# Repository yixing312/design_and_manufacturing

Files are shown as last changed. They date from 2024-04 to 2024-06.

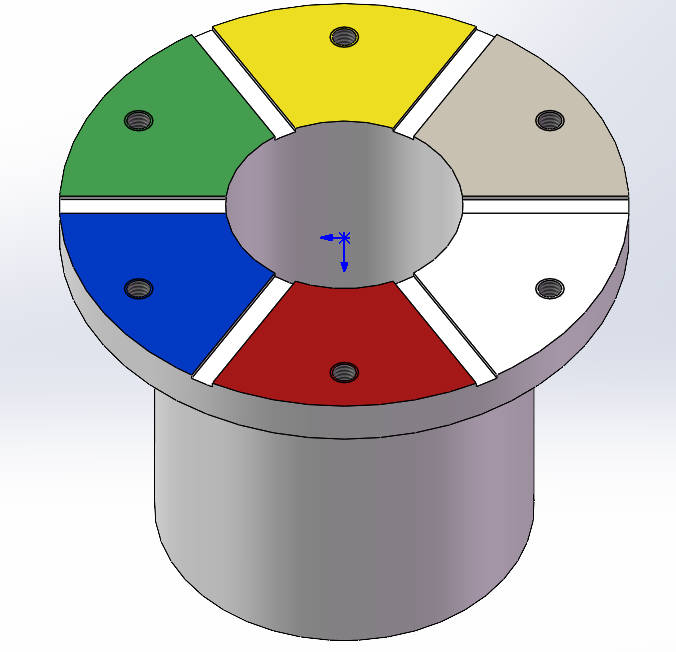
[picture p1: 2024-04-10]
建模文件/model_ver3/下法兰.jpg

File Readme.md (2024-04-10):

# README

## 文件结构

- 绘图文件
- 建模文件
- 任务说明文件
- 周期汇报
- Ansys
- data
  - Ansys
    - [4 4 4 4 4 4]
  - task_queue.txt
- scripts
  - py端分析器
  - Ansys端分析器

## 双端分析器执行逻辑

- **在 py 中运行 `py端分析器.py`**

`py端分析器.py` 中包含一个任务队列 `task_queue`，一个任务栈 `task_stack`。任务队列中存放待执行的任务，任务栈中存放已经分析完成的任务。每个任务元素都是由六个数字表示的元组，分别表示六个螺栓参数。

`py端分析器.py`持续循环查找 `"../data/task_queue.txt"` 文件，将该文件消失视为ansys分析完成，此时弹出任务队列中的元素，依次分析同轴度并压入 `ansys_ans` 栈中。将任务队列完成的任务压入任务栈中。

根据任务栈和分析结果栈中的数据，梯度下降获得下一组任务参数，将其压入任务队列中。

将任务队列写入 `"../data/task_queue.txt"` 文件，等待下一次循环。

在等待循环的过程中利用空闲时间完成上一个周期内任务的分析结果绘图等后处理工作。

- **在 Ansys 中运行 `ansys端分析器.py`**

`ansys` 中不指定初始任务，而是持续循环查找 `"../data/task_queue.txt"` 文件，将该文件出现视为py端分析完成，开始执行分析任务。

文件中每一行即为一个单独的任务，为一个元组，包括六个螺栓参数。由于读取每一行为一个字符串，可采用 `task[1:-1]..strip().split(",")` 函数将其转化为元组。

在分析完成后，将每个任务的分析结果写入 `"../data/" + str(task)` 文件中，等待py端读取。**注意，这里没有后缀，本质上就是txt文件**

完成所有分析任务后删除 `"../data/task_queue.txt"` 文件，等待下一次循环。

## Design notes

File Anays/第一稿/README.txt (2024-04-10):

by zsb ver1

1、建模导入的是zhgg的ver2版本，整体仿真参数设置过程与PPT一致

2、命名选择中，各螺栓序号与sw文件中螺栓序号一致，为7-12。用到命名选择的面有：各螺栓下表面(boltx_down)、上法兰上表面(up_up)、各螺栓
螺纹面(bolt_x)、下法兰螺纹孔内表面(down_x)、上法兰扇面(up_X)、下法兰扇面(down_X)

3、目前仿真求解项有整体总变形，以及自定义的一个截面上x方向变形量，还不能得到同轴度

4、子部件id：
bolt11 	209
bolt8  	211
bolt9	213
bolt10	215
bolt7	217
bolt12	219
获取方法：示教

5、自动化：利用文件中的calculate.py脚本，保存的结果路径为：ansys_1_files/user_files/

by the way ANSYS参数设置真麻烦啊啊啊啊啊啊

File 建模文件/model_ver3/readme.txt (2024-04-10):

Modeled by mzh, ver 3

1.原以为建模三分钟完成，后来发现因为六个扇形面高度均不一样，需要分6部分建模，稍微有点点麻烦╰（‵□′）╯

2.上下法兰均分成了6个单独的扇形，因此每个扇形（包括6条切槽）均可独立设置高度，方便结合实物修改

3.在零件图的部件树中对每个扇形、切槽、螺纹孔进行了命名，方便查找，同时不同面的染色不同

4.A面染红色，依次顺时针（正对染色面）旋转为B、C、D、E、F面

5.各个扇形高度参考“实验室已有上下法兰接触面厚度尺寸”给定

6.assemble_1~6装配时均选取相对距离最近的两个面重合，因为这两个面间距最小，重合时其他面都不会干涉

7.螺栓采用“同轴心”和表面“重合”约束，并未采用“螺旋”配合，因此实际上会产生螺纹孔与螺栓干涉的问题，
   已经评估会影响仿真！

8.assemble装配体的螺栓螺纹线为实际建模，assemble_1~assemble_6的螺纹线不存在（光轴）

9.assemble_1部件树下的螺栓顺序与扇形顺序对应关系：
	螺栓顺序    上法兰面    下法兰面    间隙（以20mm为0距离）
	1	  A	    E	    0.237	(重合面)
	2	  C	    C	    0.345
	3	  D	    B	    0.365
	4	  F	    F	    0.389
	5	  E	    A	    0.398
	6	  B	    D	    0.425

  assemble_2部件树下的螺栓顺序与扇形顺序对应关系(通过干涉检查)：
	螺栓顺序    上法兰面    下法兰面    间隙（以20mm为0距离）
	1	  A	    A	    0.282	(重合面)
	2	  C	    E	    0.323
	3	  D	    D	    0.394
	4	  F	    B	    0.419
	5	  E	    C	    0.375
	6	  B	    F	    0.366

  assemble_3部件树下的螺栓顺序与扇形顺序对应关系(通过干涉检查)：
	螺栓顺序    上法兰面    下法兰面    间隙（以20mm为0距离）
	1	  A	    B	    0.341
	2	  C	    F	    0.397
	3	  D	    E	    0.261	(重合面)
	4	  F	    C	    0.337
	5	  E	    D	    0.486
	6	  B	    A	    0.337

  assemble_4部件树下的螺栓顺序与扇形顺序对应关系(通过干涉检查)：
	螺栓顺序    上法兰面    下法兰面    间隙（以20mm为0距离）
	1	  A	    C	    0.259	(重合面)
	2	  C	    A	    0.368
	3	  D	    F	    0.335
	4	  F	    D	    0.448
	5	  E	    E	    0.353
	6	  B	    B	    0.396

  assemble_5部件树下的螺栓顺序与扇形顺序对应关系(通过干涉检查)：
	螺栓顺序    上法兰面    下法兰面    间隙（以20mm为0距离）
	1	  A	    D	    0.37
	2	  C	    B	    0.427
	3	  D	    A	    0.306	(重合面)
	4	  F	    E	    0.315
	5	  E	    F	    0.427
	6	  B	    C	    0.314
   
  assemble_6部件树下的螺栓顺序与扇形顺序对应关系(通过干涉检查)：
	螺栓顺序    上法兰面    下法兰面    间隙（以20mm为0距离）
	1	  A	    F	    0.311
	2	  C	    D	    0.456
	3	  D	    C	    0.283	(重合面)
	4	  F	    A	    0.36
	5	  E	    B	    0.457
	6	  B	    E	    0.292

猜测：选取间隙方差最小的装配方式最有利于提高同轴度喵~

以上，喵喵喵ο(=•ω＜=)ρ⌒☆（爱来自小猫娘~~~~~~(❤ ω ❤)

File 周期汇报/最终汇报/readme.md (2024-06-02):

# 鸟为什么会飞

最后一次，我们要做出最好的装配。

分析与测试有什么意义？——为了能够以最少的时间完成一次完美的装配
每一次装配，都是为了未来的某一次可以以最小的成本呈现出结果

---
第一，赋其形骨
数字化是问题抽象的第一步。

---
第二，赋其翅翼
装配相位就不是问题啊，我们测试六次不就搞定了？仿真又没多少时间

一个循环对称的函数可以写成什么样的组合呢

对于六个变量的装配问题来说，显然有一个 C6 的旋转对称性和非手性，其拥有的6个自由度恰好可以有最小自由度描述如下，由一个二次型、一个线性向、一个常数项组成

$$
f = q^{T}\begin{bmatrix}
  a & b & c & d & c & b \\
  b & a & b & c & d & c \\
  c & b & a & b & c & d \\
  d & c & b & a & b & c \\
  c & b & c & b & a & b \\
  b & c & d & c & b & a \\
\end{bmatrix}q+eq+f
$$

$$
\phi _{\text{最优}} = \phi \quad for \quad \min_{\phi}\left( Var(d_{\phi;1:3})+\alpha E(d_{\phi;C_2})+\beta E(d_{\phi;C_3})\right)
$$

---
第三，赋其色彩
仿真那么多次是为了此后遇到同样的问题不再需要仿真

---
第四，试其飞翔
最后一次，高高的飞起来吧

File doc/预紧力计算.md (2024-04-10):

# 螺栓预紧力与扭矩的计算

——by mzh

在拧紧螺母时需要克服内、外螺纹之间的螺纹力矩$T_1$和螺纹连接件与被连接件之间的支承面摩擦力矩$T_2$的和力矩：
$$
T=T_{1}+T_{2}=\frac{d_{2}} {2} F_{p} \operatorname{t a n} ( \, \psi+\rho_{v} \, ) \,+\frac{1} {3} \mu_{c} F_{p} \, \frac{D_{0}^{3}-d_{0}^{3}} {D_{0}^{2}-d_{0}^{2}}
$$
其中$d_2$螺纹中径，$\psi$螺纹升角，$\rho_v$螺纹当量摩擦角，$\mu_c$螺母端面与被连接件支承面之间的摩擦系数，$D_0,d_0$支承面的内外径，$F_p$预紧力。

通过下图确定$\mu_c$



对于普通粗牙螺纹钢制螺栓，取$\psi=1°42^″—3°2^″$，$\rho_v=\arctan(1.155\mu_c)$,$\mu_c=0.15$,$d_2≈0.9d$，$D_0≈1.7d$,$d_0≈1.1d$，带入上式，整理可得：
$$
T≈0.2F_pd
$$
故当扭矩介于3—6Nm时，根据上式可以计算得到预紧力介于2500—5000N。

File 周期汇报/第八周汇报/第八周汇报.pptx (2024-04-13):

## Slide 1

装配问题

装配大作业

选择装配相位

设置装配应力

迭代装配应力

处理分析结果

确定装配方案

Ansys

装配描述

建模文件

图纸文件

Python

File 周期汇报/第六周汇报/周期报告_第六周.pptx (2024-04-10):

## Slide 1

周期汇报
——第六周

闫济洲 张善斌 马正华

2024年4月6日

## 制图与建模

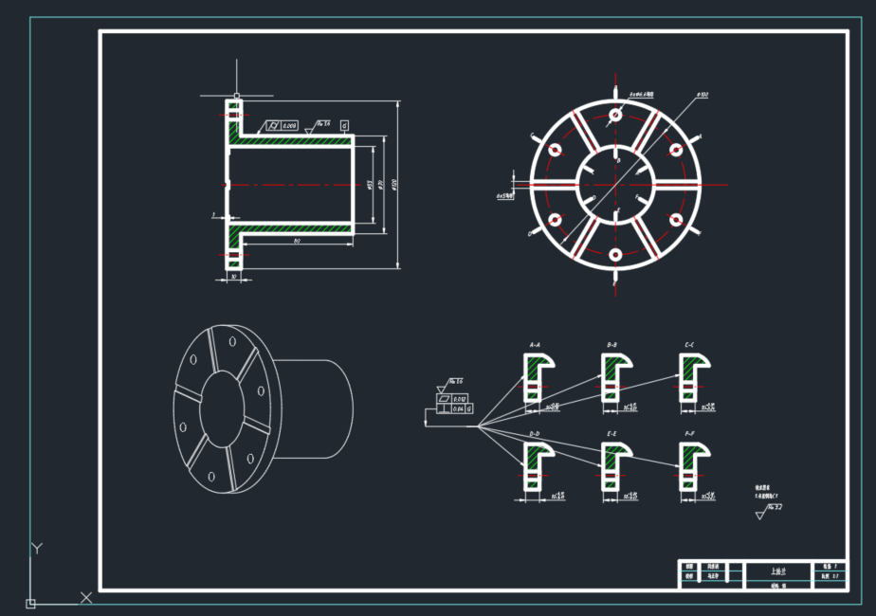
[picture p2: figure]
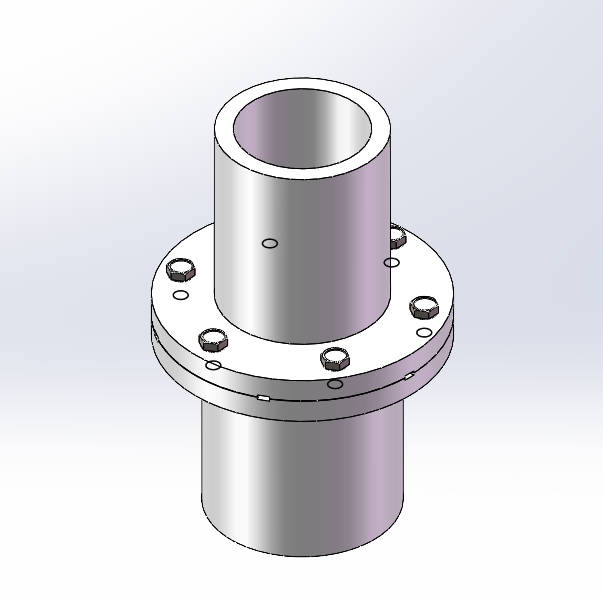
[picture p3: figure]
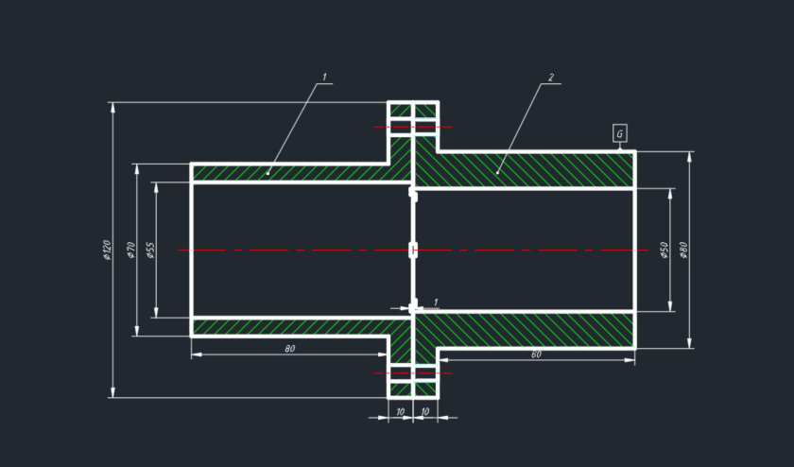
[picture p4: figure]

* 装配体文件和建模文件见附件，包括上下法兰与六种装配方式

## 装配方式分析

根据装配相位的不同共有六种装配方式，每种装配方式中可以给出每个相位面的初始间隙。

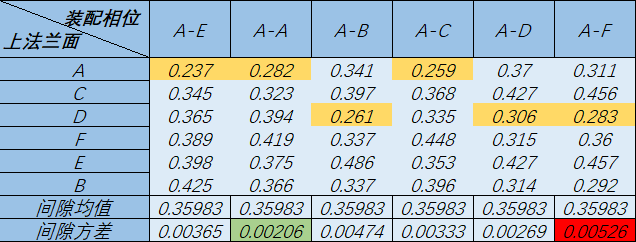
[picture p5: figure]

是否装配的初始间隙的方差最小最有利于装配后同轴度？

黄色 – 接触面
绿色 – 最小方差
红色 – 最大方差

## 有限元分析

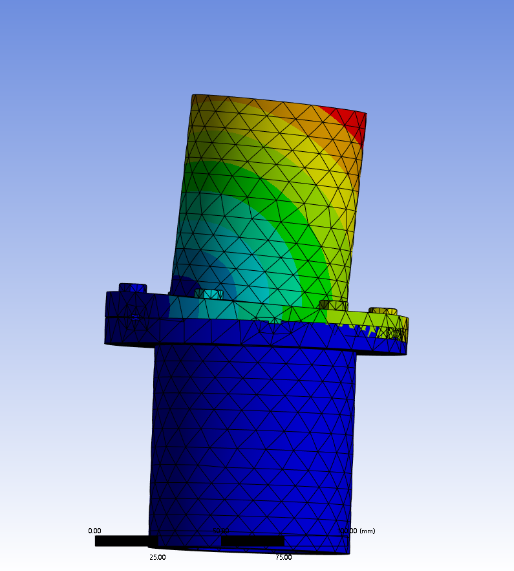
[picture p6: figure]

有限元分析过程

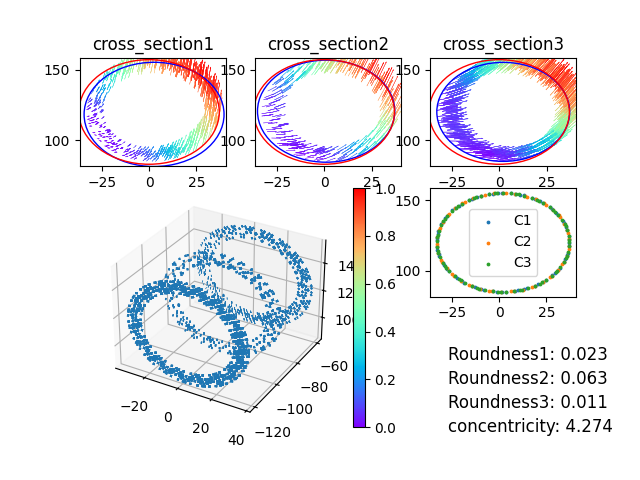
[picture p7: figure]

截面圆度、同轴度分析过程

## 有限元分析自动化

后期工作安排：

1. 运行脚本比较数据获得最佳装配及预紧力方案
2. 尝试实现软件外启动脚本并完成分析流程
3. 封装工作，实现输入各数据测量值输出最优装配方案。

- 尝试通过 python 脚本启动 Anays 分析软件并完成装配、添加网格、施加预紧力的过程。失败。
- 采用 Anays 软件内脚本，通过手动完成装配后使用 python 添加各相位预紧力。成功。

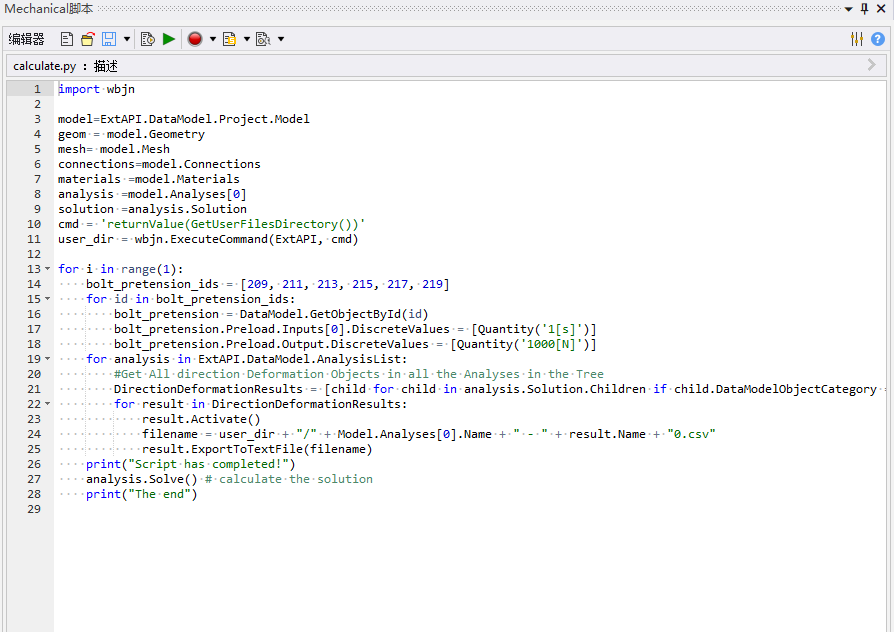
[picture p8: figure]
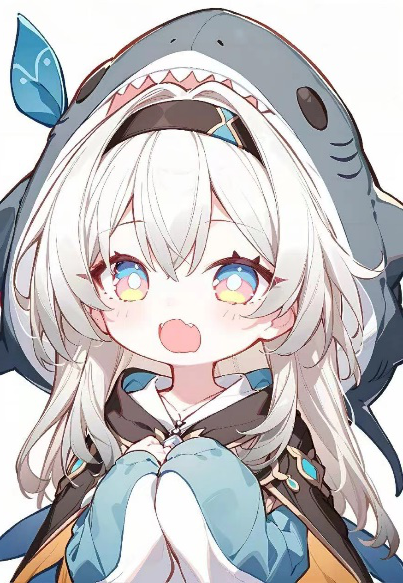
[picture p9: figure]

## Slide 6

请老师批评指正

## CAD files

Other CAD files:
绘图文件/绘图文件 ver2/上下法兰装配.dwg
绘图文件/绘图文件 ver1/上下法兰装配.dwg

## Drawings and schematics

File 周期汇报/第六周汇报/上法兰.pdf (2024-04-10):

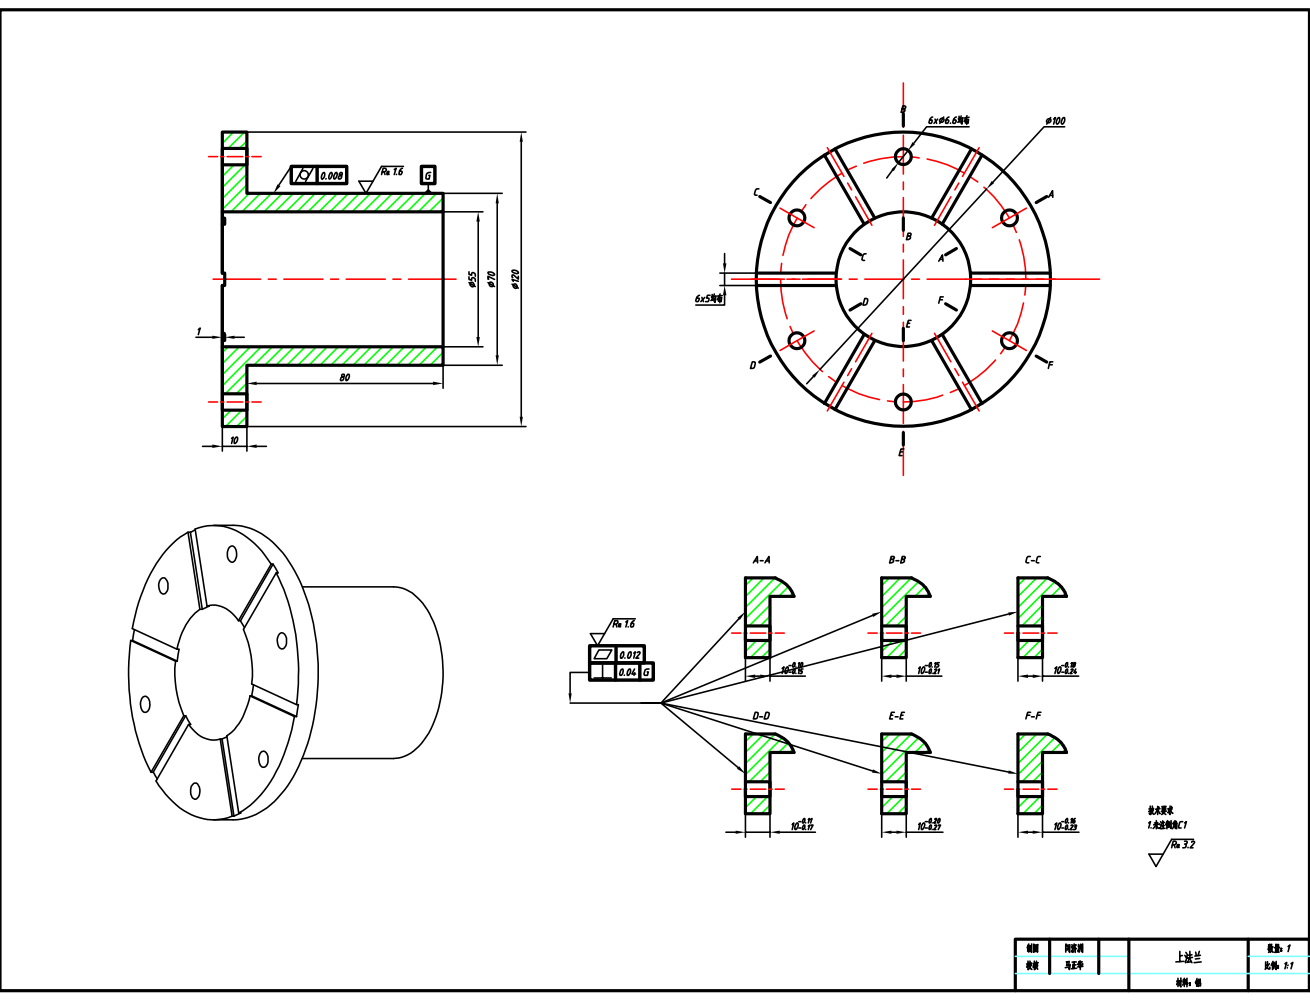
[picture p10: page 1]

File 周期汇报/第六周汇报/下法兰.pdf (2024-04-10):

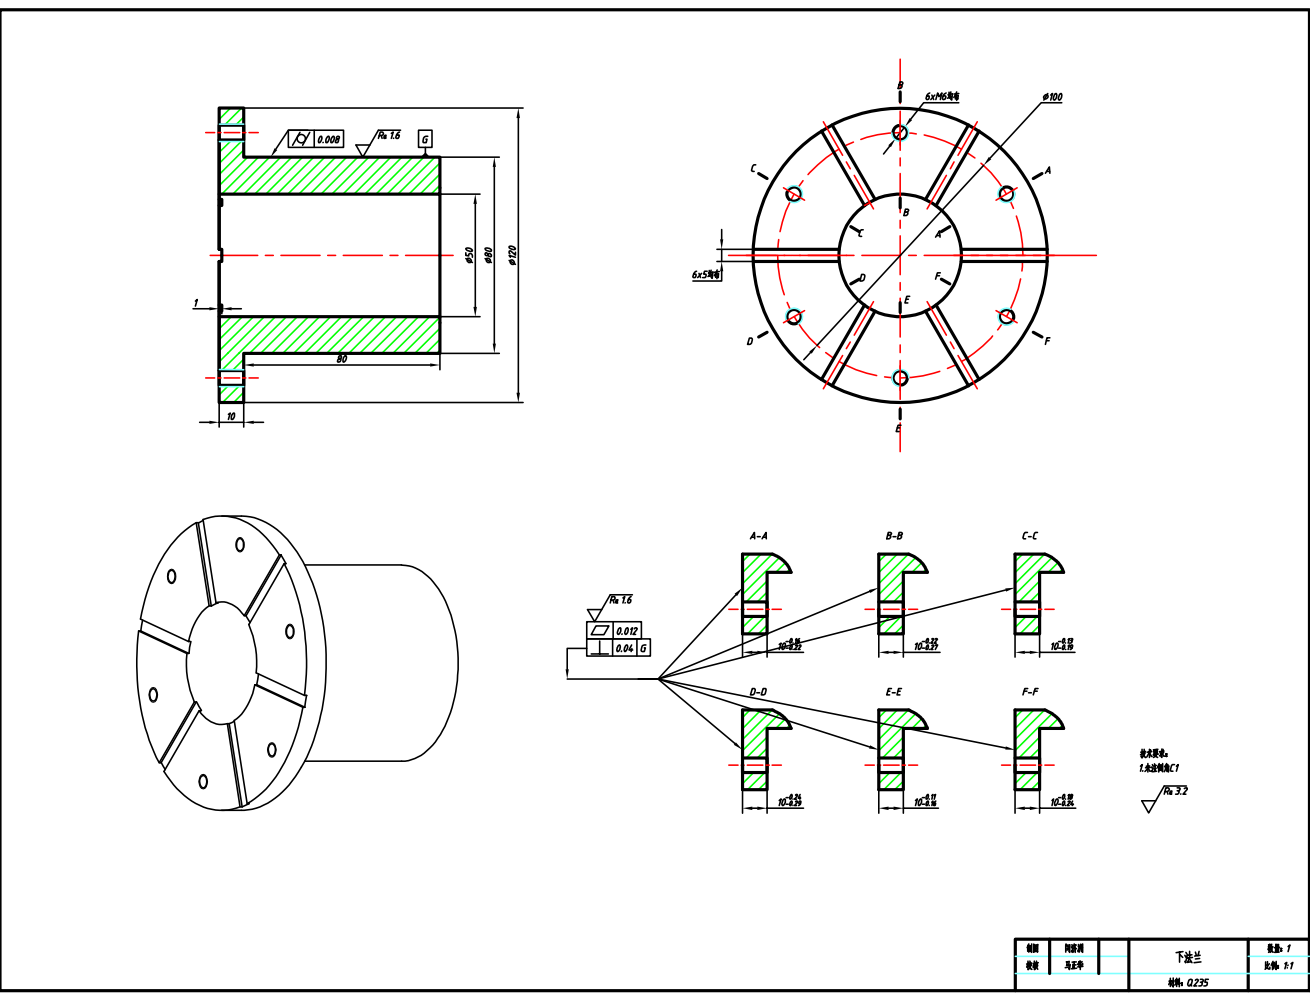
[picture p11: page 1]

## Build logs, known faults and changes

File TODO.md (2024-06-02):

# 大作业任务与阶段性成果

- [x] 任务建模与图纸绘制
  - [x] 建模文件
    - [x] 零件体
    - [x] 装配体
  - [x] 图纸绘制
    - [x] 零件体
    - [x] 装配体
- [X] 装配方案分析
  - [x] 最近截面分析
  - [X] 装配方案排序与剪枝
- [X] 有限元分析
  - [x] 静态分析（手动）
    - [x] 有限元设置并分析
    - [x] 数据后处理
  - [x] 有限元分析自动化
    - [x] Ansys-端分析器
    - [x] Python-端后处理器
    - [x] Python-端迭代算法
      - [x] 随机任务（单任务）
      - [x] 随机任务队列（多任务）
      - [x] 退火算法（单任务）
      - [x] 梯度下降法（多任务）
    - [x] Ansys-Python 通信与任务协议
    - [ ] Python-端任务迭代预测值

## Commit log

2024-04-05 下班收工
2024-04-10 第七周周三提交，想到了两端联动的办法
    [assemble.SLDASM, assemble_1.SLDASM, assemble_2.SLDASM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]
2024-04-10 双端同步的版本
2024-04-10 新鲜出锅
2024-04-10 退火算法与梯度下降法已提交，喵喵喵
2024-04-10 修缮Ansys 脚本
2024-04-10 不同的任务类型
2024-04-11 增加了循环终止流程，增加了初始化任务接口
2024-04-12 修改了路径和文件名称
    [上下法兰装配.dwg, 下法兰.dwg]
2024-04-12 改了输出格式
2024-04-12 小修小改
2024-04-12 修改文件命名问题
2024-04-12 增加 end 指示
2024-04-13 git似乎炸了的版本
    [1x.csv, 1y.csv, 2x.csv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]
2024-05-29 崭新的未来
    [间隙.xlsx]
2024-06-02 最初也是最后的不和谐音
2024-06-05 大意了啊家人们
